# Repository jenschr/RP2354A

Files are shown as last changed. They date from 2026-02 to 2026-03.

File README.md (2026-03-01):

# RP2354A
Kicad design for a minimal RP2354A based devboard, based on the original files from Raspberry Pi. Made in a small form factor, 2-layer board that can be produced anywhere. I'll update the repo with more images once I've made some copies myself.

Feel free to use this as a starting point for your own projects. [Contact me](https://maketronics.no/about/) for consulting and custom hardware based around RP2354A or other hardware.

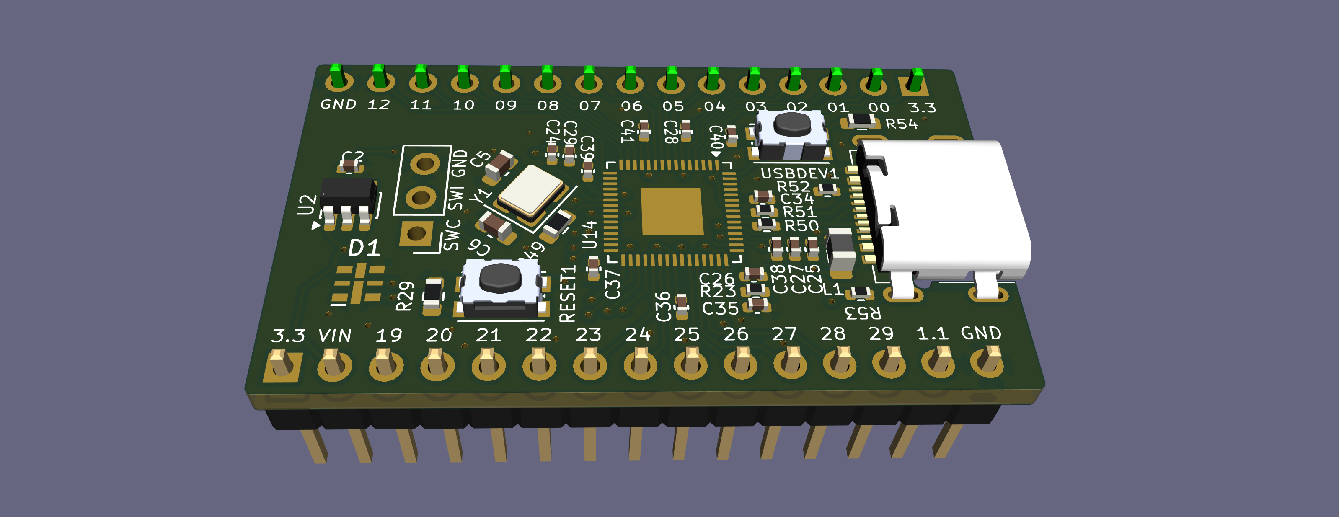
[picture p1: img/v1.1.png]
v1.1


Raspberry Pi MPN used for test board: SC1511(13)-A4.

## Versions
- v1.1 Swapped the TCR8BM33A for a more easily available and cheaper AP2112K-3.3. Takes more space, but just works. The extra space allowed one more pin on each side, so VIN/USB and IO12 is now broken out.
- v1.0 used the Toshiba LDO TCR8BM33A. This is just to fiddly for DIY boards and due to poor datasheet, I got the bias wrong.

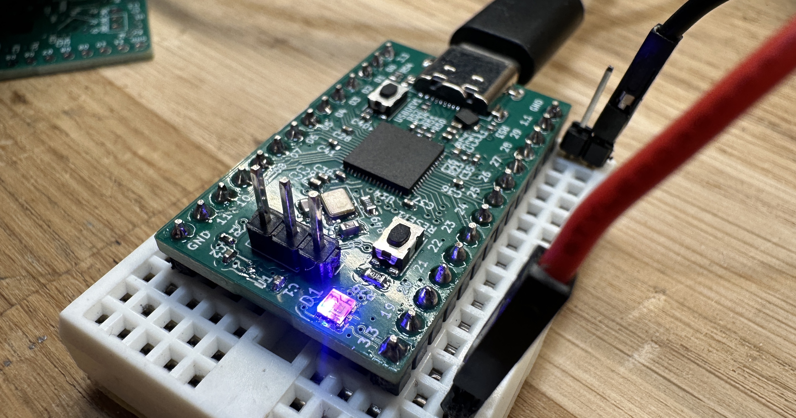
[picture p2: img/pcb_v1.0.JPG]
v1.0 pcb


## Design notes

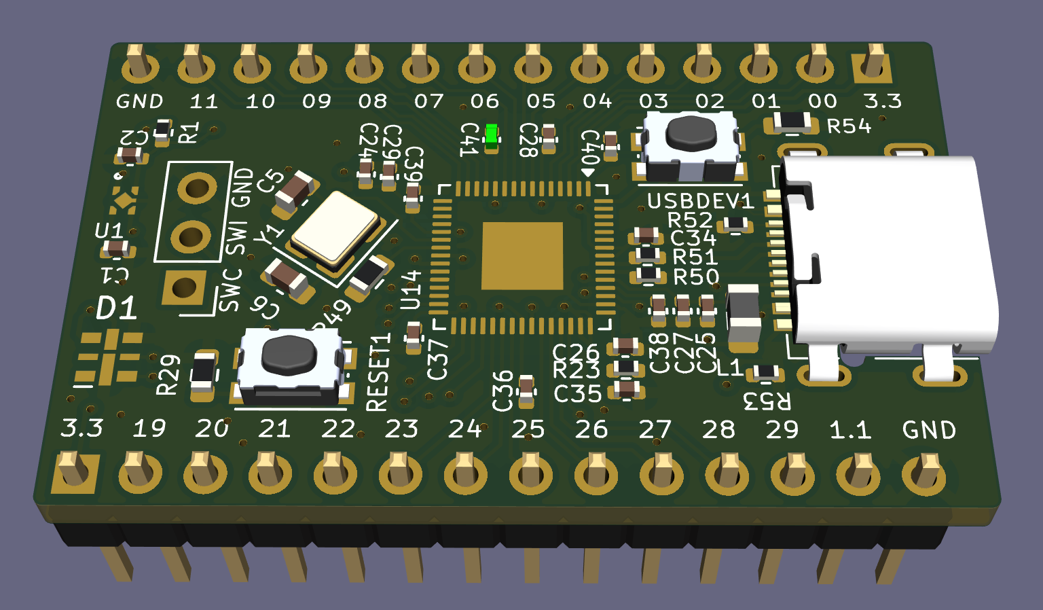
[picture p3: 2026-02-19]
img/v1.0.png

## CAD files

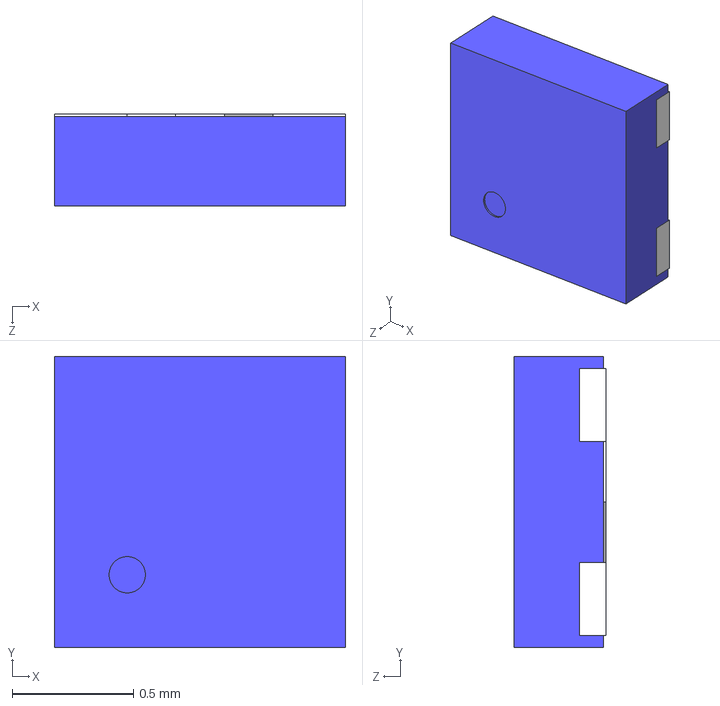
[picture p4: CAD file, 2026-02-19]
RP2354/TCR8BM33A_L3F/DFN5B.STEP
1.20 x 1.20 x 0.38 mm

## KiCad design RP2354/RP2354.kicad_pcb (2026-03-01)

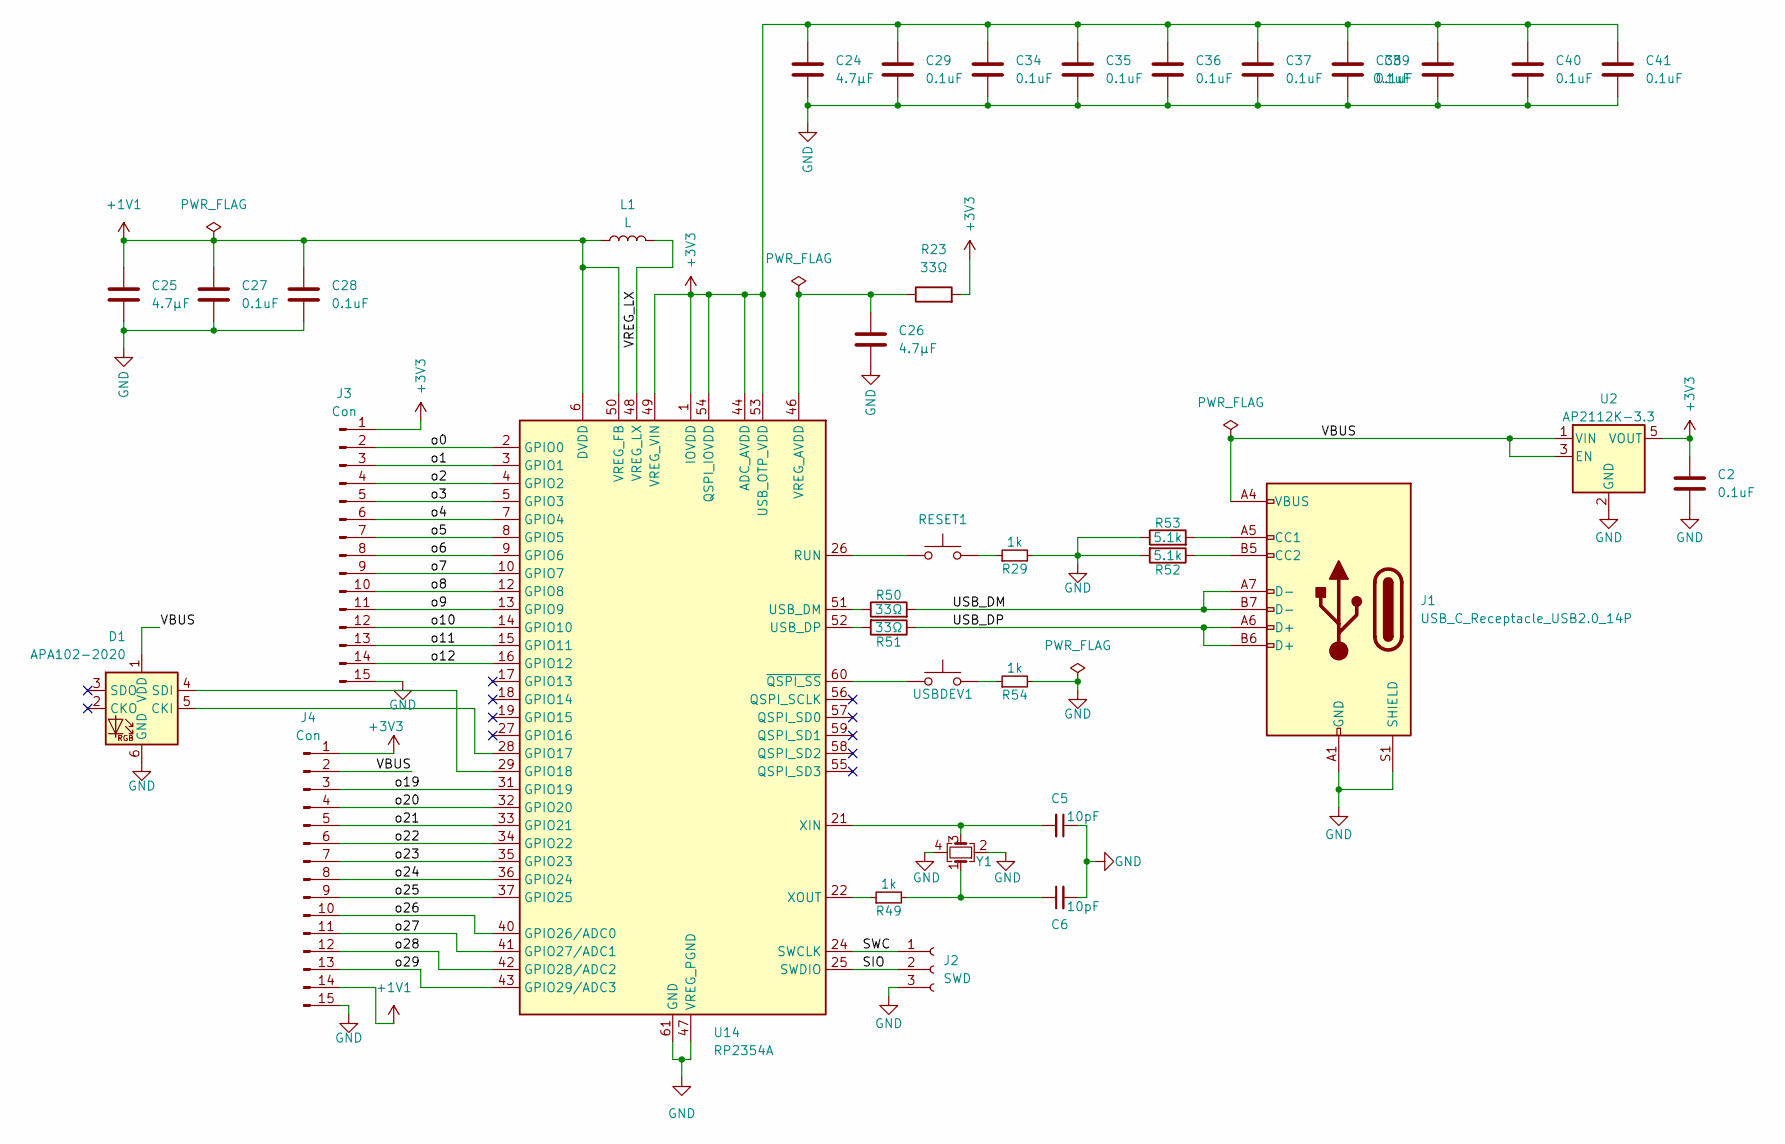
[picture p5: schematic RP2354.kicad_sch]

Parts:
C2, C27, C28, C29, C34, C35, C36, C37, C38, C39, C40, C41: 0.1uF; C_0402_1005Metric; MPN CL05B104KA5NNNC
C5, C6: 10pF; C_0603_1608Metric; MPN CL10C100JB8NFNC
C24, C25, C26: 4.7μF; C_0402_1005Metric; MPN GRM155D80E475ME47J
D1: APA102-2020; LED-APA102-2020; MPN 3341
J1: USB_C_Receptacle_USB2.0_14P; TYPE-C-31-M-14; MPN TYPE-C-31-M-14
J2: SWD; PinHeader_1x03_P2.54mm_Vertical
J3, J4: Con; PinHeader_1x15_P2.54mm_Vertical
L1: L; R_0805_2012Metric; MPN AOTA-B201610S3R3-101-T
R23, R50, R51: 33Ω; R_0402_1005Metric; MPN RC0402FR-0733RL
R29, R49, R54: 1k; R_0603_1608Metric; MPN RT0603FRE101KL
R52, R53: 5.1k; R_0402_1005Metric; MPN RC0402FR-075K1L
RESET1: SW_Push; SW_Push_1P1T_NO_CK_KMR2; MPN KMR241G LFS
U2: AP2112K-3.3; SOT-23-5; MPN AP2112K-3.3TRG1
U14: RP2354A; QFN-60-1EP_7x7mm_P0.4mm_EP3.4x3.4mm; MPN SC1511(13)-A4
USBDEV1: SW_Push; SW_Push_1P1T_NO_CK_KMR2; MPN KMR241G LFS
Y1: Crystal; Crystal_SMD_3225-4Pin_3.2x2.5mm; MPN ABM8-272-T3

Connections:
+1V1: C25.1, C27.2, C28.2, J4.14, L1.1, U14.6 (DVDD), U14.23 (DVDD), U14.39 (DVDD), U14.50 (VREG_FB)
+3V3: C2.2, C24.1, C29.2, C34.2, C35.2, C36.2, C37.2, C38.2, C39.2, C40.2, C41.2, J3.1, J4.1, R23.2, U2.5 (VOUT), U14.1 (IOVDD), U14.11 (IOVDD), U14.20 (IOVDD), U14.30 (IOVDD), U14.38 (IOVDD), U14.44 (ADC_AVDD), U14.45 (IOVDD), U14.49 (VREG_VIN), U14.53 (USB_OTP_VDD), U14.54 (QSPI_IOVDD)
/SIO: J2.2, U14.25 (SWDIO)
/SWC: J2.1, U14.24 (SWCLK)
/USB_DM: J1.A7 (D-), J1.B7 (D-), R50.2
/USB_DP: J1.A6 (D+), J1.B6 (D+), R51.1
/VBUS: D1.1 (VDD), J1.A4 (VBUS), J1.A9 (VBUS), J1.B4 (VBUS), J1.B9 (VBUS), J4.2, U2.1 (VIN), U2.3 (EN)
/VREG_LX: L1.2, U14.48 (VREG_LX)
/o0: J3.2, U14.2 (GPIO0)
/o1: J3.3, U14.3 (GPIO1)
/o2: J3.4, U14.4 (GPIO2)
/o3: J3.5, U14.5 (GPIO3)
/o4: J3.6, U14.7 (GPIO4)
/o5: J3.7, U14.8 (GPIO5)
/o6: J3.8, U14.9 (GPIO6)
/o7: J3.9, U14.10 (GPIO7)
/o8: J3.10, U14.12 (GPIO8)
/o9: J3.11, U14.13 (GPIO9)
/o10: J3.12, U14.14 (GPIO10)
/o11: J3.13, U14.15 (GPIO11)
/o12: J3.14, U14.16 (GPIO12)
/o19: J4.3, U14.31 (GPIO19)
/o20: J4.4, U14.32 (GPIO20)
/o21: J4.5, U14.33 (GPIO21)
/o22: J4.6, U14.34 (GPIO22)
/o23: J4.7, U14.35 (GPIO23)
/o24: J4.8, U14.36 (GPIO24)
/o25: J4.9, U14.37 (GPIO25)
/o26: J4.10, U14.40 (GPIO26/ADC0)
/o27: J4.11, U14.41 (GPIO27/ADC1)
/o28: J4.12, U14.42 (GPIO28/ADC2)
/o29: J4.13, U14.43 (GPIO29/ADC3)
GND: C2.1, C5.1, C6.2, C24.2, C25.2, C26.2, C27.1, C28.1, C29.1, C34.1, C35.1, C36.1, C37.1, C38.1, C39.1, C40.1, C41.1, D1.6 (GND), J1.A1 (GND), J1.A12 (GND), J1.B1 (GND), J1.B12 (GND), J1.S1 (SHIELD), J2.3, J3.15, J4.15, R29.2, R52.2, R53.1, R54.2, U2.2 (GND), U14.47 (VREG_PGND), U14.61 (GND), Y1.2, Y1.4
unnamed: C6.1, R49.2, Y1.1
unnamed: D1.5 (CKI), U14.28 (GPIO17)
unnamed: D1.4 (SDI), U14.29 (GPIO18)
unnamed: J1.A5 (CC1), R53.2
unnamed: J1.B5 (CC2), R52.1
unnamed: R29.1, RESET1.2
unnamed: R54.1, USBDEV1.2
unnamed: RESET1.1, U14.26 (RUN)
unnamed: R50.1, U14.51 (USB_DM)
unnamed: R51.2, U14.52 (USB_DP)
unnamed: C26.1, R23.1, U14.46 (VREG_AVDD)
unnamed: C5.2, U14.21 (XIN), Y1.3
unnamed: R49.1, U14.22 (XOUT)
unnamed: U14.60 (~QSPI_SS), USBDEV1.1

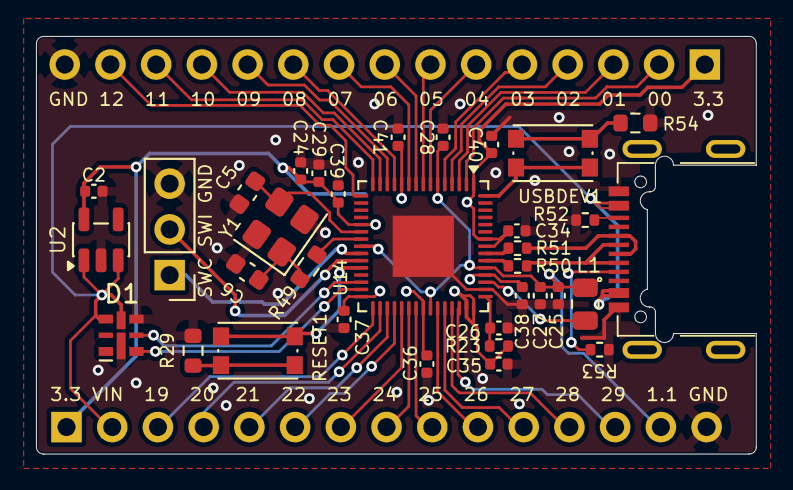
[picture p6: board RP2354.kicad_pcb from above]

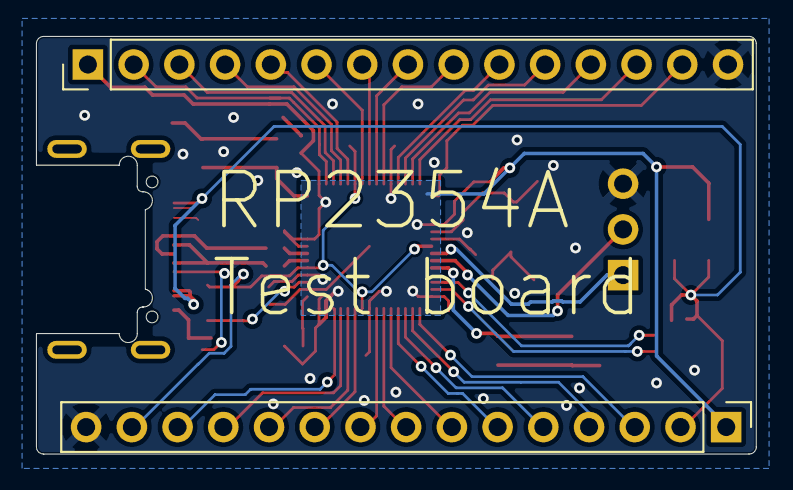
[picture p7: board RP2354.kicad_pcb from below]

Board: 2 copper layers, 40.0 x 23.2 mm, 36 parts (2 on the bottom side), 47 nets.

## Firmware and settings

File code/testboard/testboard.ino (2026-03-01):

#include <Adafruit_DotStar.h>
#define DOTSTAR_NUM 1
#define PIN_DOTSTAR_DATA 18
#define PIN_DOTSTAR_CLK 17
Adafruit_DotStar strip(DOTSTAR_NUM, PIN_DOTSTAR_DATA, PIN_DOTSTAR_CLK, DOTSTAR_BRG);

void setup() {
  strip.begin(); // Initialize pins for output
  strip.setBrightness(20);
  strip.show();  // Turn all LEDs off ASAP
}

void loop() {
  rainbow(10);             // Flowing rainbow cycle along the whole strip
}

void rainbow(int wait) {
  for(long firstPixelHue = 0; firstPixelHue < 5*65536; firstPixelHue += 256) {
    for(int i=0; i<strip.numPixels(); i++) { // For each pixel in strip...
      int pixelHue = firstPixelHue + (i * 65536L / strip.numPixels());
      strip.setPixelColor(i, strip.gamma32(strip.ColorHSV(pixelHue)));
    }
    strip.show(); // Update strip with new contents
    delay(wait);  // Pause for a moment
  }
}

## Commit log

2026-02-19 v1.0 files as sent to JLC
    [DFN5B.STEP, RP2354.kicad_pcb, RP2354.kicad_sch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]
2026-02-19 Quick pass at ERC
    [RP2354.kicad_sch]
2026-02-19 MPN's added for most parts. iBom export
    [RP2354.kicad_pcb, RP2354.kicad_sch]
2026-03-01 Updated with a larger 3.3V regulator. The added pins break out +5V/USB and IO12 as well. The TCR8BM is just too fiddly for DIY boards and the datasheet isn't good enough.
    [RP2354.kicad_pcb, RP2354.kicad_sch, bom.csv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]
2026-03-01 Layout tweak. Doc update.
    [RP2354.kicad_pcb]
2026-03-01 Swapped for larger inductor footprint on L1. 0805 resistor is correct.
    [RP2354.kicad_pcb, RP2354.kicad_sch]
